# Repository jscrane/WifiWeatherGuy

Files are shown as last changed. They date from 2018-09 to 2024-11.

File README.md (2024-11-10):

View this project on [CADLAB.io](https://cadlab.io/project/1280). 

# WiFiWeatherGuy
WeatherGuy for ESP8266.

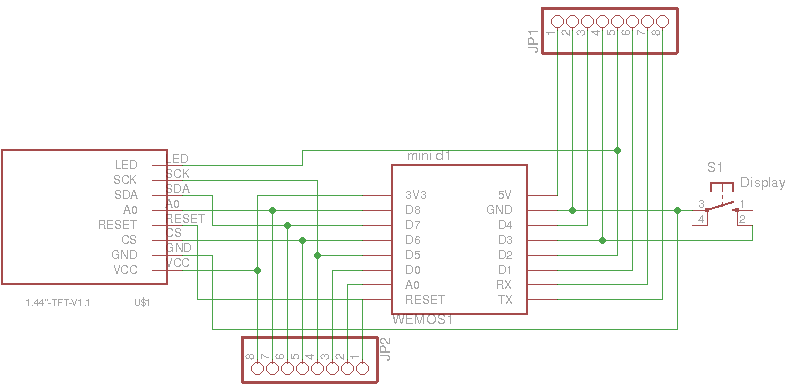
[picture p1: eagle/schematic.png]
Schematic


## Hardware
- Wemos D1 Mini
- ILI9163-based TFT display, see [here](http://henrysbench.capnfatz.com/henrys-bench/arduino-displays/arduino-1-44-in-spi-tft-display-tutorial/)

## Software
- Arduino 1.8.9
- [TFT_eSPI library](https://github.com/Bodmer/TFT_eSPI) 2.5.43
- [ESP8266 for Arduino](https://github.com/esp8266/Arduino.git) 3.1.2
- [Arduino ESP8266 filesystem uploader](https://github.com/esp8266/arduino-esp8266fs-plugin)
- [ArduinoJson](http://arduinojson.org/) 7.2.0
- [Timezone](https://github.com/JChristensen/Timezone) 1.2.4
- [Time](https://github.com/PaulStoffregen/Time) 1.6
- [SimpleTimer](https://github.com/schinken/SimpleTimer)

## Installation
- Get an API key for your Provider (required for OpenWeatherMap, not for Open Meteo)
- Edit data/config.json with your preferences
- Configure your display in TFT_eSPI/User_Setup.h (if using the Arduino IDE), otherwise edit Makefile
- Configure your timezone in zone.h
- Upload the filesystem (Tools > ESP8266 Sketch Data Upload)
- Upload the sketch

## Note
The weather icons must be 24-bit bitmaps; convert from GIF as follows:

    % convert foo.gif -type truecolor foo.bmp 

The [Airycon](https://github.com/HaroleDev/Airycons) icons used by the Open Meteo provider were
converted using the GIMP, exporting the PNG files as 24-bit BMPs.

## Providers

### Open Weather Map
A previously supported provider was [OpenWeatherMap](https://openweathermap.org).

However as-of 2024-11-04 its version 2.5 API is deprecated in favour of version 3.0 which
requires registration of a credit card.

Limitations of this API are:
- astronomy: moon age, phase
- forecasts: forecasts in the free API are every 3 hours and you get 40 of
them, which is too big to parse on an ESP8266
- the credit-card thing

Its code remains for reference, for now.

### Open Meteo
The latest provider is [Open-Meteo](https://open-meteo.com/en/docs).

Limitations of this API are:
- astronomy: moon age, phase
- no forecast humidity

### Meterologisk
If bad things happen to Open Meteo, the next provider is
[Meterologisk](https://github.com/jscrane/WifiWeatherGuy/issues/27).

## Credits
- Javascript [transparency](https://github.com/leonidas/transparency)
- WMO [icons](https://weather-sense.leftium.com/wmo-codes)

The Finished Article

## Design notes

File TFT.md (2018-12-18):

TFT boards
==========

David Prentice's 
[st7735_readreg](https://github.com/prenticedavid/TFT_SPI_kbv) 
sketch is useful to identify chipsets in various cheap 1.44" TFT displays.

| SPI | TFT | Pin |
| --- | --- | --- |
| MOSI | SDA | 11 |
| SCK | SCK | 13 |
| SS  | CS  | 10 |
| DC  | AO  | 9 |

KMR1441_SPI V2
--------------
The backlight LED doesn't seem to be variable with PWM on this board.
Set CPPFLAGS to this in the Makefile for this display:

```
CPPFLAGS = -DVERSION=\"${shell date +%F}\" -DST7735_GREENTAB \
	-DUSER_SETUP_LOADED -DST7735_DRIVER -DTFT_WIDTH=128 -DTFT_HEIGHT=128 \
	-DTFT_CS=PIN_D6 -DTFT_DC=PIN_D8 \
	-DTFT_RST=-1 -DSPI_FREQUENCY=27000000 -DLOAD_GLCD
```

```
Bi-directional Read registers

controller reg(0x01) = 0x00
ST7735S reg(0x04) = 0x7C89F0
ST7735S reg(0x09) = 0x610000
ST7735S reg(0x0A) = 0x08
ST7735S reg(0x0B) = 0x00
ST7735S reg(0x0C) = 0x06
ST7735S reg(0x0D) = 0x00
ST7735S reg(0x0E) = 0x00
ST7735S reg(0x0F) = 0x00
ST7735S reg(0x2E) = 0x102008
ST7735S reg(0xDA) = 0x7C
ST7735S reg(0xDB) = 0x89
ST7735S reg(0xDC) = 0xF0
```

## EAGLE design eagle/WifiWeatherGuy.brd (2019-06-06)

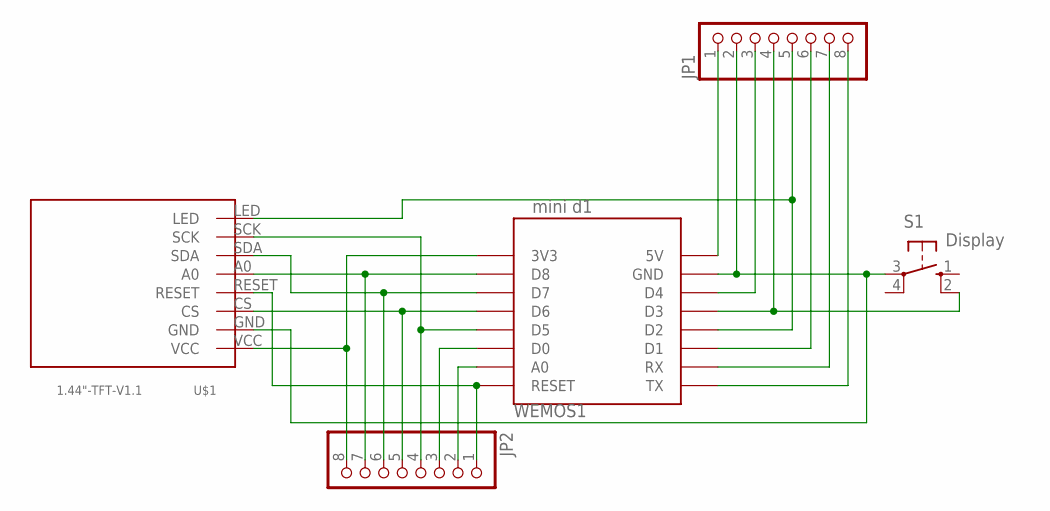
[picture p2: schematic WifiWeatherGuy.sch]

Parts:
JP1, JP2: PINHD-1X8; 1X08
S1: Display; B3F-10XX
U$1: 1.44"-TFT-V1.1; 1.44-TFT-V1.1
WEMOS1: mini d1; WEMOS-D1-MINI

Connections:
unnamed: JP2.8, U$1.VCC, WEMOS1.3V3
unnamed: JP2.5, U$1.CS, WEMOS1.D6
unnamed: JP2.7, U$1.A0, WEMOS1.D8
unnamed: JP2.6, U$1.SDA, WEMOS1.D7
unnamed: JP2.4, U$1.SCK, WEMOS1.D5
unnamed: JP1.5, U$1.LED, WEMOS1.D2
unnamed: JP2.3, WEMOS1.D0
unnamed: JP2.1, U$1.RESET, WEMOS1.RESET
unnamed: JP1.4, S1.2 (S1), WEMOS1.D3
unnamed: JP1.1, WEMOS1.5V
unnamed: JP1.3, WEMOS1.D4
unnamed: JP1.6, WEMOS1.D1
unnamed: JP1.7, WEMOS1.RX
unnamed: JP1.8, WEMOS1.TX
unnamed: JP2.2, WEMOS1.A0
unnamed: JP1.2, S1.3, U$1.GND, WEMOS1.GND

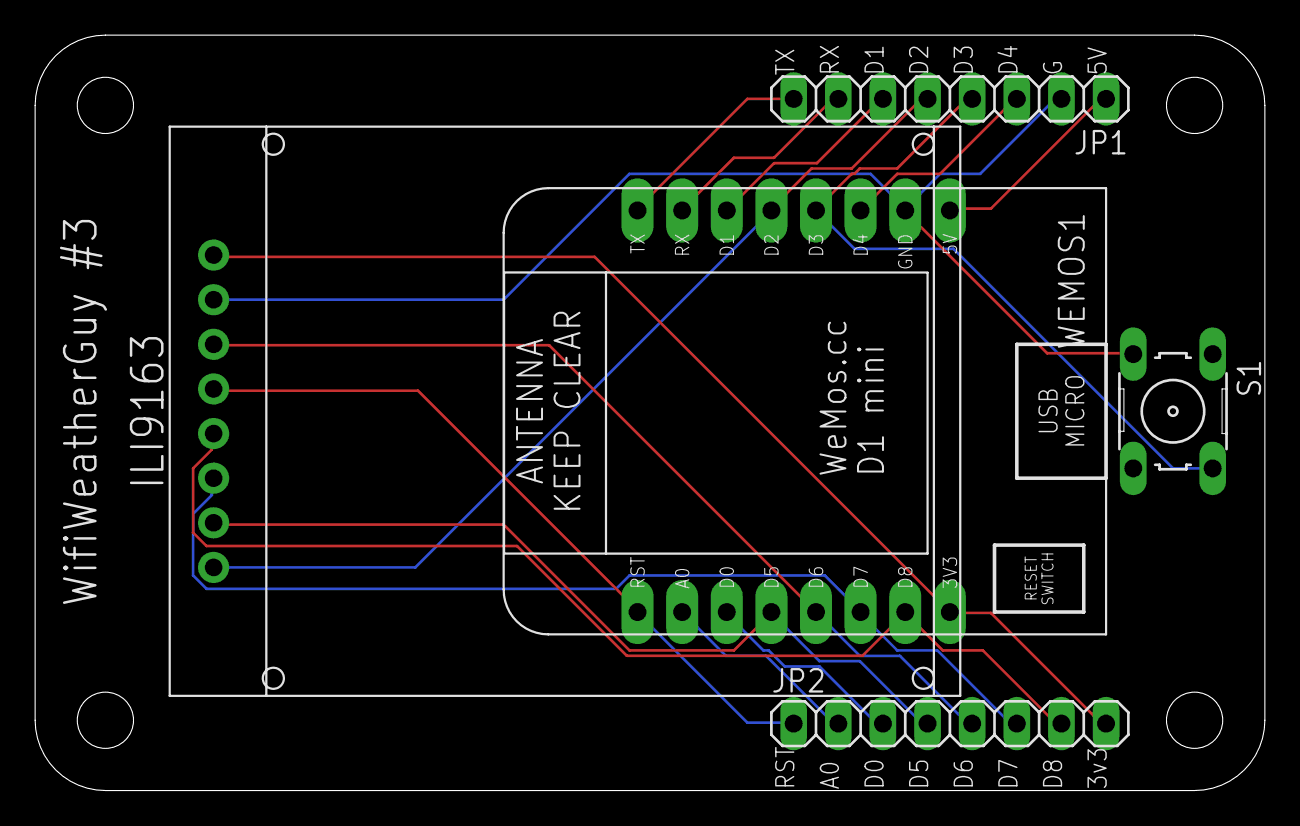
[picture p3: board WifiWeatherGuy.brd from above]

Board: 2 copper layers, 70.0 x 43.0 mm, 6 parts (0 on the bottom side), 16 nets.

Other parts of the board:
U$2: DP7043_V1

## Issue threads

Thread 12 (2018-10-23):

Getting nearest weather station

jscrane, 2018-10-23:
- [x] ip to lat/long, [see here](http://ip-api.com/json)
- [x] nearest weather station, [example](http://api.wunderground.com/api/a75da485666047dd/geolookup/conditions/q/53.34399,-6.26719.json)

jscrane, 2018-10-24:
```
const size_t bufferSize = JSON_OBJECT_SIZE(14) + 290;
DynamicJsonBuffer jsonBuffer(bufferSize);

const char* json = "{\"as\":\"AS6830 Liberty Global Operations B.V.\",\"city\":\"Dublin\",\"country\":\"Ireland\",\"countryCode\":\"IE\",\"isp\":\"Virgin Media Ireland\",\"lat\":53.3331,\"lon\":-6.2489,\"org\":\"Virgin Media Ireland\",\"query\":\"89.101.216.154\",\"region\":\"L\",\"regionName\":\"Leinster\",\"status\":\"success\",\"timezone\":\"Europe/Dublin\",\"zip\":\"D02\"}";

JsonObject& root = jsonBuffer.parseObject(json);

const char* as = root["as"]; // "AS6830 Liberty Global Operations B.V."
const char* city = root["city"]; // "Dublin"
const char* country = root["country"]; // "Ireland"
const char* countryCode = root["countryCode"]; // "IE"
const char* isp = root["isp"]; // "Virgin Media Ireland"
float lat = root["lat"]; // 53.3331
float lon = root["lon"]; // -6.2489
const char* org = root["org"]; // "Virgin Media Ireland"
const char* query = root["query"]; // "89.101.216.154"
const char* region = root["region"]; // "L"
const char* regionName = root["regionName"]; // "Leinster"
const char* status = root["status"]; // "success"
const char* timezone = root["timezone"]; // "Europe/Dublin"
const char* zip = root["zip"]; // "D02"
```

jscrane, 2018-10-24:
```
	const __FlashStringHelper *host = F("ip-api.com");
	if (client.connect(host, 80)) {
		client.print(F("GET /json HTTP/1.1\r\nHost: "));
		client.print(host);
		client.print(F("\r\nConnection: close\r\n\r\n"));
		if (client.connected()) {
			unsigned long now = millis();
			while (!client.available())
				if (millis() - now > 5000)
					return false;
			client.find("\r\n\r\n");
			// ...
			JsonObject &root = buffer.parseObject(client);
			// if success, decode...
			float lat = root["lat"];
			float lon = root["lon"];
			snprintf(cfg.station, sizeof(cfg.station), "%f,%f", lat, lon);
		}
	}
```

Closed 2018-10-24.

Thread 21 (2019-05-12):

Get working with latest TFT_eSPI

jscrane, 2019-05-12:
Currently it's stuck at version 1.3.8.

Version 1.4.3 won't compile and 1.4.4 doesn't handle the Adafruit display_bmp() code correctly.

Closed 2019-06-01.

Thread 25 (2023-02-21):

WeatherAPI Weather Provider

jscrane, 2023-02-21:
https://www.weatherapi.com/docs/

jscrane, 2024-11-11:
```/current.json```

```
{
  "location": {
    "name": "New York",
    "region": "New York",
    "country": "United States of America",
    "lat": 40.71,
    "lon": -74.01,
    "tz_id": "America/New_York",
    "localtime_epoch": 1658522976,
    "localtime": "2022-07-22 16:49"
  },
  "current": {
    "last_updated_epoch": 1658522700,
    "last_updated": "2022-07-22 16:45",
    "temp_c": 34.4,
    "temp_f": 93.9,
    "is_day": 1,
    "condition": {
      "text": "Partly cloudy",
      "icon": "//cdn.weatherapi.com/weather/64x64/day/116.png",
      "code": 1003
    },
    "wind_mph": 16.1,
    "wind_kph": 25.9,
    "wind_degree": 180,
    "wind_dir": "S",
    "pressure_mb": 1011,
    "pressure_in": 29.85,
    "precip_mm": 0,
    "precip_in": 0,
    "humidity": 31,
    "cloud": 75,
    "feelslike_c": 37,
    "feelslike_f": 98.6,
    "vis_km": 16,
    "vis_miles": 9,
    "uv": 8,
    "gust_mph": 11.6,
    "gust_kph": 18.7,
    "air_quality": {
      "co": 293.70001220703125,
      "no2": 18.5,
      "o3": 234.60000610351562,
      "so2": 12,
      "pm2_5": 13.600000381469727,
      "pm10": 15,
      "us-epa-index": 1,
      "gb-defra-index": 2
    }
  }
}
```

jscrane, 2024-11-11:
```/astronomy.json```

```
{
  "location": {
    "name": "New York",
    "region": "New York",
    "country": "United States of America",
    "lat": 40.71,
    "lon": -74.01,
    "tz_id": "America/New_York",
    "localtime_epoch": 1658522976,
    "localtime": "2022-07-22 16:49"
  },
  "astronomy": {
    "astro": {
      "sunrise": "05:10 AM",
      "sunset": "09:03 PM",
      "moonrise": "12:29 AM",
      "moonset": "04:01 PM",
      "moon_phase": "Third Quarter",
      "moon_illumination": "42"
    }
  }
}
```

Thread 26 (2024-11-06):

Open Meteo Provider

jscrane, 2024-11-06:
Combined weather data from multiple national weather centres.

[API docs](https://open-meteo.com/en/docs)

jscrane, 2024-11-06:
All current conditions.

`$ curl -X GET --header 'Accept: application/json' 'hapi.open-meteo.com/v1/forecast?latitude=53.3146&longitude=-6.275&hourly=temperature_2m&timezone=auto&current=temperature_2m,relative_humidity_2m,apparent_temperature,is_day,precipitation,rain,showers,snowfall,weather_code,cloud_cover,pressure_msl,surface_pressure,wind_speed_10m,wind_direction_10m,wind_gusts_10m&forecast_days=0'
{"latitude":53.323345,"longitude":-6.2775116,"generationtime_ms":0.12993812561035156,"utc_offset_seconds":0,"timezone":"Europe/Dublin","timezone_abbreviation":"GMT","elevation":39.0,"current_units":{"time":"iso8601","interval":"seconds","temperature_2m":"°C","relative_humidity_2m":"%","apparent_temperature":"°C","is_day":"","precipitation":"mm","rain":"mm","showers":"mm","snowfall":"cm","weather_code":"wmo code","cloud_cover":"%","pressure_msl":"hPa","surface_pressure":"hPa","wind_speed_10m":"km/h","wind_direction_10m":"°","wind_gusts_10m":"km/h"},"current":{"time":"2024-11-06T10:15","interval":900,"temperature_2m":15.6,"relative_humidity_2m":88,"apparent_temperature":15.6,"is_day":1,"precipitation":0.00,"rain":0.00,"showers":0.00,"snowfall":0.00,"weather_code":1,"cloud_cover":39,"pressure_msl":1027.0,"surface_pressure":1022.3,"wind_speed_10m":7.6,"wind_direction_10m":113,"wind_gusts_10m":15.8},"hourly_units":{"time":"iso8601","temperature_2m":"°C"},"hourly":{"time":[],"temperature_2m":[]}}`

jscrane, 2024-11-06:
See API page for WMO Weather Interpretation Codes.

jscrane, 2024-11-09:
Still to do:
- [ ] forecast humidity: optional, don't display if not available from provider
- [ ] current pressure: rising/falling, optional a.a.
- [ ] local time vs GMT
- [ ] geocoding lat/lon from city

Closed 2024-11-10.

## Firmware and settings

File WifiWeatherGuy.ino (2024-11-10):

#include <ArduinoJson.h>
#include <SPI.h>
#include <LittleFS.h>
#include <Adafruit_GFX.h>
#include <TFT_eSPI.h>
#include <ESP8266WiFi.h>
#include <DNSServer.h>
#include <ESP8266mDNS.h>
#include <ESP8266WebServer.h>
#include <ESP8266HTTPUpdateServer.h>
#include <SimpleTimer.h>
#include <TimeLib.h>
#include <Timezone.h>

#include "Switch.h"
#include "Configuration.h"
#include "state.h"
#include "display.h"
#include "dbg.h"
#include "providers.h"

#if !defined(TFT_LED)
#define TFT_LED	D2
#endif

#if !defined(SWITCH)
#define SWITCH	D3
#endif

TFT_eSPI tft;
MDNSResponder mdns;
ESP8266WebServer server(80);
ESP8266HTTPUpdateServer httpUpdater;
DNSServer dnsServer;

uint32_t display_on;
uint8_t fade;
bool connected, debug;

config cfg;
Timezone *tz;
struct Conditions conditions;
struct Forecast forecasts[4];
struct Statistics stats;

#if !defined(PROVIDER)
#define PROVIDER OpenWeatherMap
#endif

PROVIDER provider;

Switch swtch(500);
void IRAM_ATTR swtch_handler() { swtch.on(); }

const char *config_file = "/config.json";
static int screen = 0;
static SimpleTimer timers;

static void update_display() {
	if (cfg.dimmable || fade > cfg.dim) {
		switch (screen) {
		case 0:
			display_weather(conditions);
			break;
		case 1:
			display_astronomy(conditions);
			break;
		case 2:
		case 3:
		case 4:
		case 5:
			display_forecast(forecasts[screen - 2]);
			break;
		case 6:
			display_about(stats);
			break;
		}
	}
}

// timer callbacks
static void update_conditions() {
	DBG(println(F("Updating conditions...")));
	if (provider.fetch_conditions(conditions)) {
		update_display();
		stats.last_fetch_conditions = millis();
	}
}

static void update_forecasts() {
	DBG(println(F("Updating forecasts...")));
	if (provider.fetch_forecasts(&forecasts[0], sizeof(forecasts)/sizeof(forecasts[0])))
		stats.last_fetch_forecasts = millis();
}

static void next_fade() {
	analogWrite(TFT_LED, --fade);
	if (fade == cfg.dim && screen > 0) {
		screen = 0;
		update_display();
	}
}

static void turn_off() {
	if (cfg.dimmable) {
		timers.setTimer(25, next_fade, cfg.bright - cfg.dim);
	} else {
		tft.fillScreen(TFT_BLACK);
		fade = cfg.dim;
	}
}

void setup() {
	Serial.begin(115200);
	tft.init();
	tft.setTextColor(TFT_WHITE, TFT_BLACK);
	tft.setCursor(0, 0);

#if defined(FONT)
	tft.setTextFont(FONT);
#endif

	pinMode(SWITCH, INPUT_PULLUP);
	debug = digitalRead(SWITCH) == LOW;

	bool result = LittleFS.begin();
	if (!result) {
		ERR(print(F("LittleFS!")));
		return;
	}

	if (!cfg.read_file(config_file)) {
		ERR(print(F("config!")));
		return;
	}

	tz = new Timezone(cfg.summer, cfg.winter);

	fade = cfg.bright;
	analogWrite(TFT_LED, fade);

	tft.fillScreen(TFT_BLACK);
	tft.setRotation(cfg.rotate);
	tft.println(F("Weather Guy (c)2018-24"));
	tft.print(F("ssid: "));
	tft.println(cfg.ssid);
	tft.print(F("password: "));
	tft.println(cfg.password);
	tft.print(F("key: "));
	tft.println(cfg.key);
	tft.print(F("station: "));
	if (cfg.nearest)
		tft.println(F("nearest"));
	else
		tft.println(cfg.station);
	tft.print(F("hostname: "));
	tft.println(cfg.hostname);
	tft.print(F("condition...: "));
	tft.println(cfg.conditions_interval);
	tft.print(F("forecast...: "));
	tft.println(cfg.forecasts_interval);
	tft.print(F("display: "));
	tft.println(cfg.on_time);
	tft.print(F("metric: "));
	tft.println(cfg.metric);
	if (cfg.dimmable) {
		tft.print(F("bright: "));
		tft.println(cfg.bright);
		tft.print(F("dim: "));
		tft.println(cfg.dim);
	} else
		tft.println(F("not dimmable"));
	if (debug)
		tft.println(F("DEBUG"));

	WiFi.mode(WIFI_STA);
	WiFi.setSleepMode(WIFI_NONE_SLEEP);
	WiFi.hostname(cfg.hostname);
	if (*cfg.ssid) {
		WiFi.setAutoReconnect(true);
		WiFi.begin(cfg.ssid, cfg.password);
		const char busy[] = "|/-\\";
		int16_t y = tft.getCursorY();
		for (int i = 0; i < 60 && WiFi.status() != WL_CONNECTED; i++) {
			delay(500);
			char c = busy[i % 4];
			tft.print(c);
			tft.setCursor(0, y);
		}
		connected = WiFi.status() == WL_CONNECTED;
	}

	server.on("/config", HTTP_POST, []() {
		if (server.hasArg("plain")) {
			String body = server.arg("plain");
			File f = LittleFS.open(config_file, "w");
			f.print(body);
			f.close();
			server.send(200);
			WiFi.setAutoConnect(false);
			ESP.restart();
		} else
			server.send(400, "text/plain", "No body!");
	});
	server.serveStatic("/", LittleFS, "/index.html");
	server.serveStatic("/config", LittleFS, config_file);
	server.serveStatic("/js/transparency.min.js", LittleFS, "/transparency.min.js");
	server.serveStatic("/info.png", LittleFS, "/info.png");

	httpUpdater.setup(&server);
	server.begin();

	if (mdns.begin(cfg.hostname, WiFi.localIP())) {
		DBG(println(F("mDNS started")));
		mdns.addService("http", "tcp", 80);
	} else
		ERR(println(F("Error starting mDNS")));

	if (!connected) {
		WiFi.mode(WIFI_AP);
		WiFi.softAP(cfg.hostname);
		tft.println(F("Connect to SSID"));
		tft.println(cfg.hostname);
		tft.println(F("to configure WiFi"));
		dnsServer.start(53, "*", WiFi.softAPIP());
	} else {
		DBG(println());
		DBG(print(F("Connected to ")));
		DBG(println(cfg.ssid));
		DBG(println(WiFi.localIP()));

		tft.println();
		tft.print(F("http://"));
		tft.print(WiFi.localIP());
		tft.println('/');

		provider.begin();

		stats.last_fetch_conditions = -cfg.conditions_interval;
		stats.last_fetch_forecasts = -cfg.forecasts_interval;
	}
	attachInterrupt(SWITCH, swtch_handler, FALLING);

	timers.setInterval(cfg.conditions_interval, update_conditions);
	timers.setInterval(cfg.forecasts_interval, update_forecasts);
	timers.setTimeout(cfg.on_time, turn_off);

	update_conditions();
	update_forecasts();
}

void loop() {
	mdns.update();

	server.handleClient();
	if (!connected) {
		dnsServer.processNextRequest();
		return;
	}

	if (swtch) {
		if (fade == cfg.dim) {
			fade = cfg.bright;
			if (cfg.dimmable)
				analogWrite(TFT_LED, fade);
			else
				update_display();
			timers.setTimeout(cfg.on_time, turn_off);
		} else {
			if (screen >= 6)
				screen = 0;
			else
				screen++;
			update_display();
		}
	}
	timers.run();
}

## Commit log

2017-08-29 turn off display after 30s
    [config.txt]
2017-08-30 OTA + mDNS
    [config.txt]
2017-08-31 add schematic
2017-10-10 update layout
    [wifiweatherguy.brd]
2017-10-10 switch time
2017-10-11 separate intervals for fetching conditions and forecasts
    [config.txt]
2017-10-16 hostname and mDNS
    [config.txt]
2017-10-17 initial config webserver
    [Configuration.h, config.txt]
2017-10-17 Revert "foo"
    This reverts commit fdb8c502c89abde9c2a589aa2e289df4e479be5d.
    [config.txt]
2017-10-17 Revert "initial config webserver"
    This reverts commit efaf6ef058dbe314636bdc0de18a4fd0c97a1003.
    [Configuration.h, config.txt]
2017-10-18 config as json
    [Configuration.h, config.txt]
2017-11-01 set WiFi hostname correctly
    [WifiWeatherGuy.ino]
2017-11-02 replace ArduinoOTA with HTTPUpdateServer
    [WifiWeatherGuy.ino]
2017-11-03 add upgrade button
2017-11-06 reset to current conditions on fade out
    [WifiWeatherGuy.ino]
2017-11-19 reboot after update config
    [WifiWeatherGuy.ino]
2018-01-06 display astronomy after current conditions
2018-01-06 enable serial debugging if button pressed at startup
2018-01-06 break out gerbers
    [WifiWeatherGuy.GBL, WifiWeatherGuy.GBO, WifiWeatherGuy.GBS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]
2018-01-08 v2 gerbers
    [WifiWeatherGuy.GBL, WifiWeatherGuy.GBO, WifiWeatherGuy.GBS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]
2018-01-12 PROGMEM string constants; don't update display unless epoch changes; WifiClient memory leak fix
    [WifiWeatherGuy.ino]
2018-01-14 more defaults for missing fields; timeout on http fetch
    [WifiWeatherGuy.ino]
2018-03-09 PWM is 0..1023
2018-03-17 switch to TFT_eSPI
2018-05-29 tiny update
    [Configuration.h]
2018-09-07 add wemos pin headers
    [WifiWeatherGuy.brd, WifiWeatherGuy.sch]
2018-09-08 v3 gerbers
    [WifiWeatherGuy.sch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]
2018-11-16 fix #14 captive portal
    [WifiWeatherGuy.ino]
2019-03-08 break out wunderground
    [Configuration.h]
2019-03-10 owm bugfixes
    [Configuration.h]
2019-06-08 update ArduinoJson to v6.x; improve debugging
    [Configuration.h]
2019-06-15 add timers and startors; remove retry interval
2019-12-10 add default provider if undefined for arduino ide compatibility
2019-12-13 more arduino compat
2019-12-19 restructure loop() using timers
2020-05-15 replace Stator with Switch
    [WifiWeatherGuy.ino]
2020-05-25 fix #23
    [Configuration.h]
2023-01-22 bugfix for non-dimmable display
    [WifiWeatherGuy.ino]
2024-11-10 26 open meteo provider (#28)
    - Open Meteo client
    - Remove Wunderground client
    - New icons from Airycons
    - ArduinoJson v7
    [Configuration.h]

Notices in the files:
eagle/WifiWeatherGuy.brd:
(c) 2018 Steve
